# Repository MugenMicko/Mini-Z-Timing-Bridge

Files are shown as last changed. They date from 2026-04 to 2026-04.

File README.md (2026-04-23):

# Mini-Z-Timing-Bridge
##A 2020 extrusion based Timing Bridge for Mini Z racing on Kyosho/RCP Tracks

This is my personal design for a 2020 Aluminium Extrusion Timing Bridge for Mini Z Racing on Kyosho / RCP Branded Tile track system\
The included bill of materials is to facilitate the EasyLaps Timing System specifications to ensure best reliability.\
The Transponder sensors sit approximately 5 mm lower than the top extrusion that I refer to as a Cross beam.  The sensors bolt directly to the extrusion with 2 M3x14mm SS SHCS (Socket Head Cap Screws) or BHCS (Button Head Cap Screws), 2 M3 washers and 2 M3 Roll In Spring T nuts.\
The bottom extrusions are connected to the upright using a blind joint and M5x12mm BHCS, as does the cross beam to the uprights\
There is an additional brace for each side that I had laser cut in 3mm aluminium sheet, which I cleaned, primed and painted before assembly. This is used to brace the bottom extrusion and uprights using M5x8mm BHCS, M5 Washers and M5 Roll In Spring T nuts.\
This solution makes the timing bridge incredibly strong and quick to disassemble with simply loosening off the top 2 M5 BHCS leaving the uprights to slide off. It was suggested by Mark Warren to utilise folding hinges with https://a.co/d/0cxLSGS9 these from Amazon.  If using this option, you will need to shorten the uprights by 4cm / 40mm.\
There appears to be contention about the height of the bridge, EasyLaps specifies 50-70cm in the manual, Phillip Ng on the 1:28 World Mini Z Community has suggested 48cm, the design makes the sensors 49.6mm from the track surface, if you wish to lower it, just shorten the uprights by you choice.\
It has also come to my attention that some clubs are using the TrackMate system and Moe Agha has stated that the ideal height range for that system is 9 to 12 inches off the track surface.  If you wish to use this bridge with that system, I have included files for a smaller bracket and would shorten the uprights to between 250 - 280mm.\
The system has been tested successfully with an EasyLaps system with out local club and found to resolve any missed lap issues we have had.\
The plastic covers on the corner of the cross beam and feet are only there to protect people and objects from potential sharp edges and are NOT structural.\

##BOM
1. 2 x 490mm long 2020 Aluminium Extrusion with both ends tapped for M5 BHCS (Uprights) (these can be reduced to 270mm for trackmate system)
2. 2 x 400mm long 2020 Aluminium Extrusion with both ends tapped for M5 BHCS and a central hole of 5mm drilled through for the blind joint faster (Bottom)
3. 1 x 1006mm long 2020 Aluminium Extrusion with 2 5mm holes drilled through 10mm from each end of the extrusion in the same direction to facilitate blind joint faster (Cross Beam)
4. 10 x M5 Roll In Spring T Nuts
5. 14 x M5 x 10 BHCS
6. 10 x M5 Washers
7. 4 x M5 x 12 BHCS (10mm version will also work)
8. 6 x M3 x 14 BHCS
9. 2 x M3 x 8 BHCS
10. 8 x M3 Washers
11. 2 x Laser cut brackets (braket V4 for Easylaps, Small Bracket for TrackMate)
12. 3D printed parts for protectors and EasyLaps Interface holder (Optional items)

I was able to get my brackets cut through a local supplier but I have also confirmed the bracket cutting files are compatible with SendCutSend, JLCPCB and PCBWay if you have noone local to you to cut them
I was able to order extrusion cut to length from a supplier in Melboure, there are a variety of resellers of 2020 extrusion all over the work including the likes of Mitsumi etc
I chose to drill and tap the extrusion myself, it is quite easy with hand tools and a drill and plenty of videos on YouTube to show you how to do it.  

Should you wish to use this timing bridge across a 3 tile setup, simply measure the width between the bumpers on the track and add 126mm\
This design will yeild an incredibly sturdy timing bridge that you can easily add to and modify. For example, it is very easy using T Nuts and M3 BHCS to mount signage for your local club to it, and beyond this, it cost me $122 AUD to build, which is about $80 USD.

Best of luck to you and I hope this Timing Bridge is useful and I would love to see photos or videos of your build in action
Cheers

Micko

Mini Z Timing Bridge

Open Community License (OCL) v1.0

Copyright (c) 2026 Michael Overland

This hardware design is licensed under the Open Community License ("OCL") v1.0.
By downloading or using the design files (STEP, CAD, STL, etc.), you agree to
the following terms:

1. LICENSE GRANT
You are granted a worldwide, non-exclusive, free-of-charge license to use,
copy, modify, and create derivative works from the design files for personal
or internal business use.

2. COMMERCIAL RESTRICTION
You MAY NOT sell, distribute, or profit from the commercial sale of the
physical product or its derivatives made from these design files without a
separate, written agreement with the Copyright Holder.

3. PATENT RIGHTS
The Copyright Holder grants you a perpetual, royalty-free patent license to
make, have made, use, and sell the design, provided that the activity complies
with Section 2.

4. NO WARRANTY
This design is provided "as-is" without any warranty.

For more information or to request a commercial license, contact:
Michael Overland
mugenmicko@gmail.com
+61437804172

Example of Blind Joint using M5 Button Head Screw
Access to M5 Screw
Assembled Timing Bridge


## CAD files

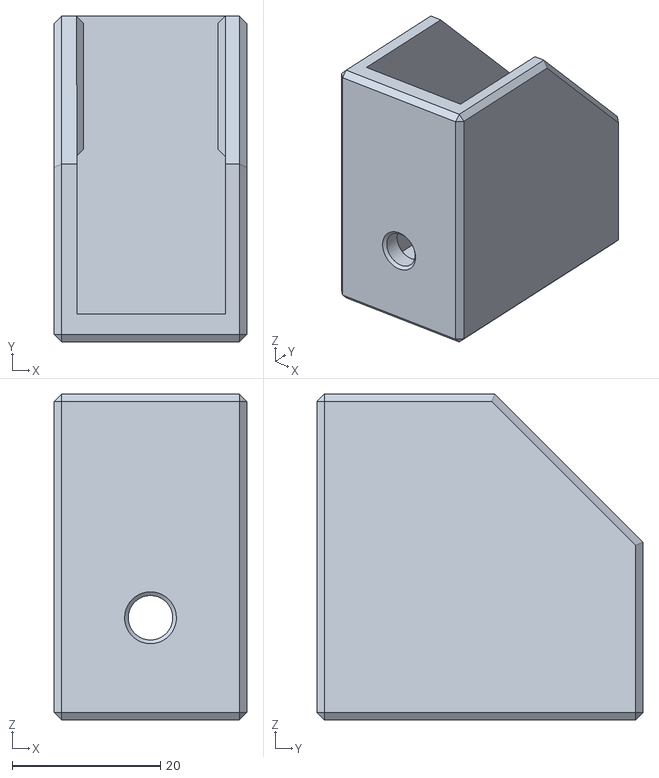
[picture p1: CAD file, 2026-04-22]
Corner Cover V2.stl
26.0 x 44.0 x 44.0

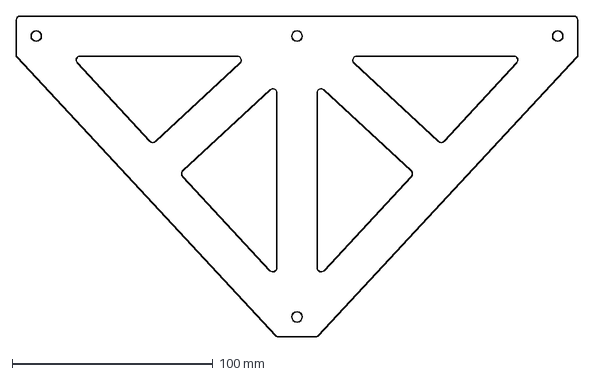
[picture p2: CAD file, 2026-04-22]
Smaller Triangulated Brace.dxf
280.0 x 160.0 mm

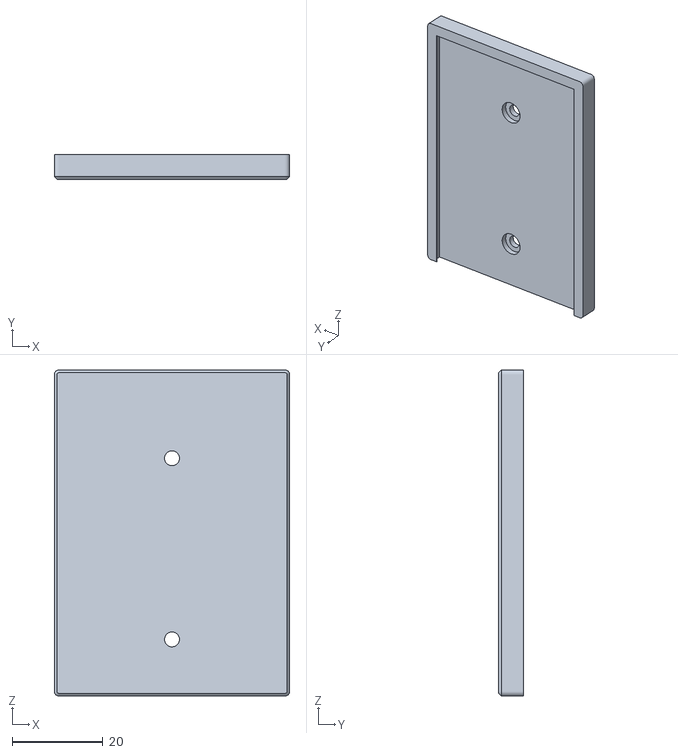
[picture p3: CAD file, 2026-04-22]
EasyLap Interface Holder.stl
52.0 x 5.50 x 72.0

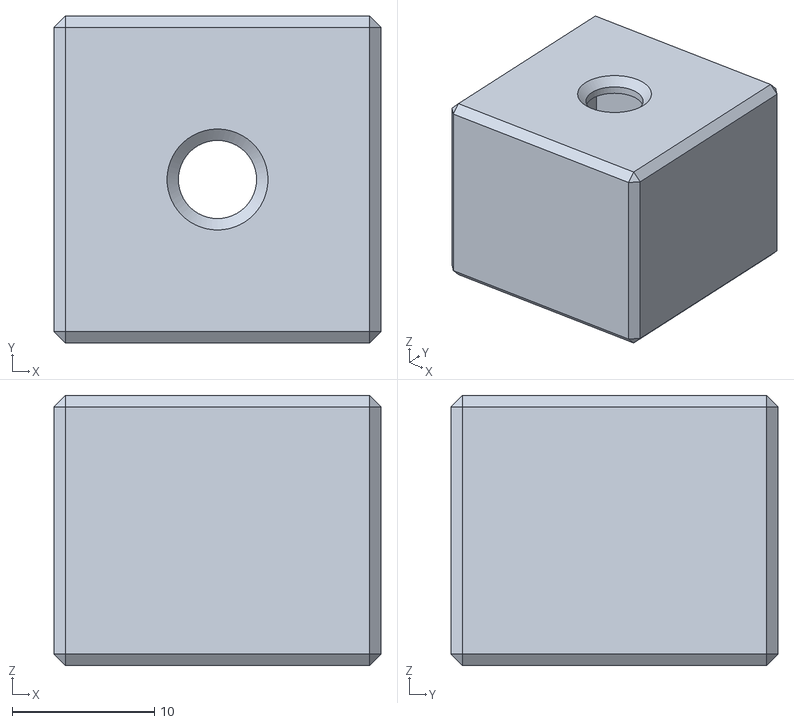
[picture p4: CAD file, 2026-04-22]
EndCap.stl
23.0 x 23.0 x 19.0

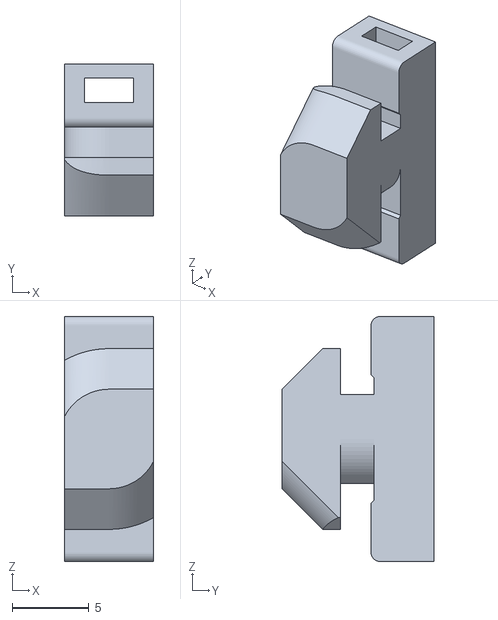
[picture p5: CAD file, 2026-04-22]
Ribbon Clip.stl
5.80 x 9.90 x 16.0

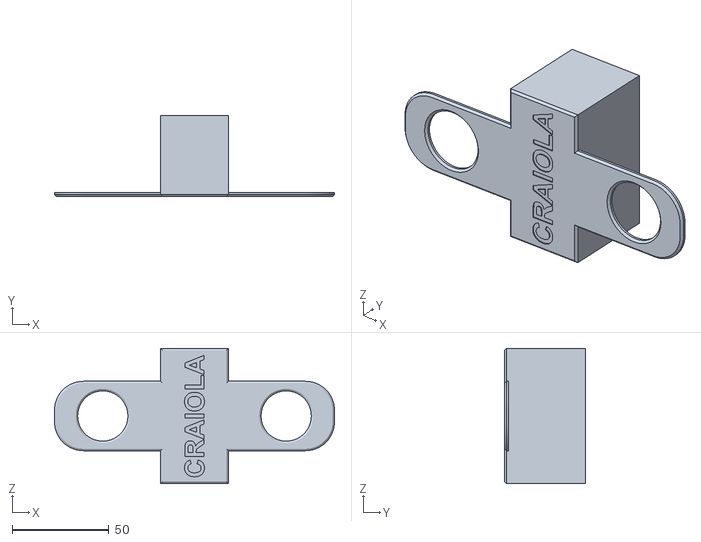
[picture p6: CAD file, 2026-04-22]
Craiola Track Spacer.stl
145.0 x 42.0 x 70.0

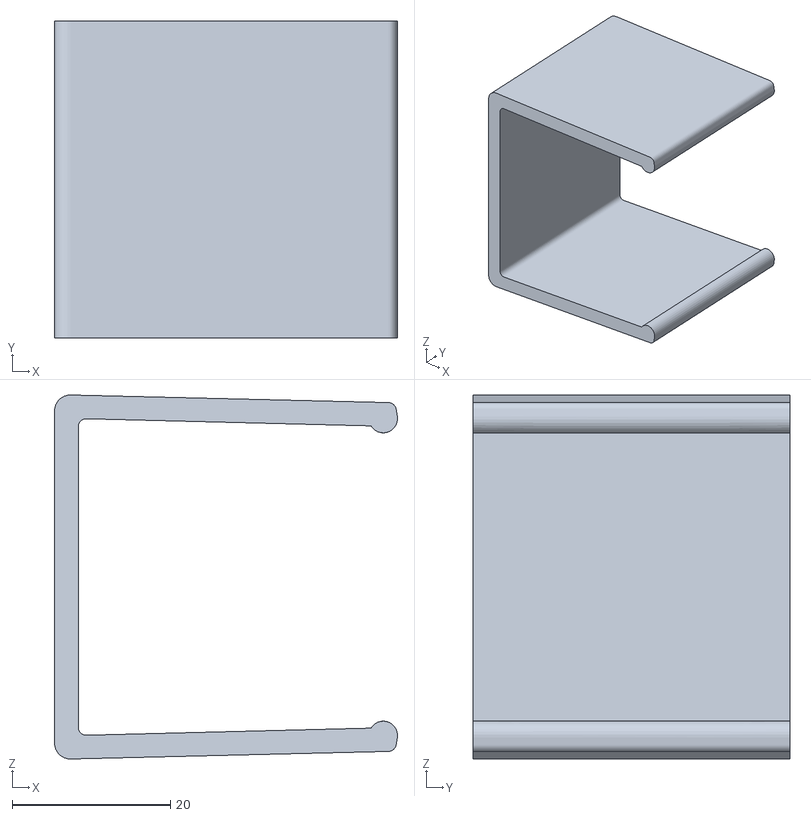
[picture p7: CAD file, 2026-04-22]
Track Clip.stl
43.3 x 40.0 x 46.0

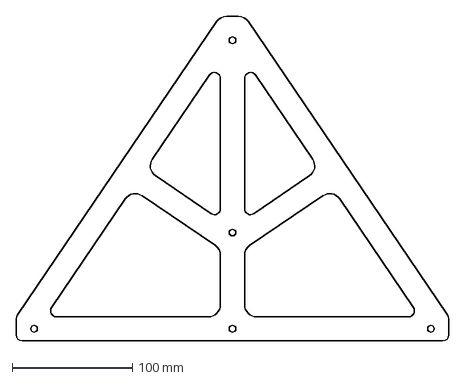
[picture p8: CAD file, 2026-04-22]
Bracket Version 4.dxf
360.0 x 270.0 mm

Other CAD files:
Track Timing Bridge.f3d

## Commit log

2026-04-22 Initial File Commit
    Initial Files upload for distribution
    [Bracket Version 4.dxf, Corner Cover V2.stl, Craiola Track Spacer.stl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]
2026-04-22 Enhance README with detailed design and BOM
    Expanded the README with detailed design and assembly instructions for the Mini-Z Timing Bridge, including specifications, materials, and compatibility notes.
2026-04-22 Revise BOM section in README for better readability
    Updated BOM section to use a numbered list format for clarity.
